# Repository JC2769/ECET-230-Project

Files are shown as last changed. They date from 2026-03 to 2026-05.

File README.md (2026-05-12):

# Personalized Weather Station

By: Joshua Chary & Shival Panchal

## Overview

The Personalized Weather Station is a custom embedded environmental monitoring system designed to measure:

- Temperature
- Humidity
- Atmospheric Pressure

The project was developed as part of ECET 230 and focuses on:

- Embedded system design
- PCB development
- Environmental sensing
- USB communication
- Manufacturing preparation
- Real-world engineering troubleshooting

The final system uses:
- ATmega328P-A microcontroller
- BME280 environmental sensor
- CH340C USB-to-serial interface
- Dual USB-C connections
- Python-based monitoring software

The project evolved from an early Raspberry Pi and DHT22 proof-of-concept into a smaller and more realistic custom PCB-based embedded system.

---

# Final System Features

## Hardware Features

- ATmega328P-A microcontroller
- BME280 environmental sensor
- CH340C USB-to-serial communication
- Dedicated USB-C power input
- Dedicated USB-C communication port
- 3.3V voltage regulation
- Crystal oscillator
- ISP programming header
- Test points for debugging
- Status LED
- ERC/DRC verified PCB design

## Software Features

- USB serial communication
- Python-based environmental monitoring
- Real-time graphing
- Weather trend estimation
- ntfy notification support
- Environmental data processing

---

# Included Project Files

This repository includes:

- Final Report
- Bill of Materials (BOM)
- Gerber Files
- Drill Files
- PCB Ordering Instructions
- Original Project Definition
- Updated Project Definition
- Source Code / Software

---

# Development Path

The project originally began as a Raspberry Pi and DHT22 proof-of-concept system used to validate environmental sensing concepts.

As development progressed, the project transitioned toward:
- A custom PCB design
- ATmega328P-A embedded system
- BME280 environmental sensing
- USB serial communication
- Python-based software integration

This redesign created a more realistic and manufacturable embedded product.

---

# Major Components

| Component | Purpose |
|---|---|
| ATmega328P-A | Main embedded microcontroller |
| BME280 | Temperature, humidity, and pressure sensing |
| CH340C | USB-to-serial communication |
| USB-C Connectors | Power and communication interfaces |
| LD1117S33TR | 3.3V voltage regulator |
| Crystal Oscillator | Stable MCU timing |
| ISP Header | Firmware programming |
| Test Points | Validation and debugging |

---

# PCB Design

The PCB was designed in KiCad and includes:

- Schematic capture
- PCB layout and routing
- ERC verification
- DRC verification
- Gerber generation
- Drill file export
- BOM generation
- 3D board rendering

The project also explored 4-layer PCB concepts to better understand:
- Inner-layer routing
- Via management
- PCB stackups
- Professional PCB workflows

---

# Manufacturing Readiness

The project includes:
- Gerber files
- Drill files
- BOM
- PCB ordering instructions

The PCB can be fabricated using:
- JLCPCB
- PCBWay
- OSHPark

The project should still be considered an educational prototype until physically assembled and fully validated.

---

# User Workflow

1. Connect the dedicated USB-C power connector
2. Connect the USB-C communication port to the computer
3. Launch the Python monitoring application
4. Environmental data is transferred through USB serial communication
5. The software graphs and processes the readings
6. ntfy notifications may be sent during demonstration operation

---

# Lessons Learned

This project provided practical experience with:
- Embedded system design
- PCB routing and layout
- Hardware troubleshooting
- USB communication
- Voltage regulation
- Manufacturing preparation
- Engineering documentation

Major lessons learned included:
- Incorrect sensor pin labeling can damage hardware
- Design reviews improve PCB quality
- Proper decoupling is critical for stable operation
- Real engineering projects evolve significantly during development

---

# Contributors

Joshua Chary
- Documentation
- Troubleshooting documentation
- PCB review assistance
- Project organization
- Presentation preparation

Shival Panchal
- PCB layout
- Hardware integration
- Embedded system implementation
- Schematic development

---

# Course Information

Institution: New Jersey Institute of Technology (NJIT)  
Course: ECET 230

---

# Final Notes

The Personalized Weather Station demonstrates the complete engineering workflow from proof-of-concept development through manufacturable PCB preparation.

The project combines:
- Embedded hardware
- Environmental sensing
- PCB manufacturing preparation
- USB communication
- Software integration
- Engineering documentation

into a realistic embedded system design experience.

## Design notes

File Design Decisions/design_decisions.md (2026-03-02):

# Environmental Sensor Subsystem – Design Decisions

## 1. Sensor Selection Decision

### Final Decision
Use the DHT22 (AM2302) as the primary environmental sensor for the proof-of-concept prototype.

### Original Plan
The initial system design included the BME280 sensor to measure pressure, temperature, and humidity.

### Issue Encountered
The BME280 modules received were unreliable and produced inconsistent or non-functional readings during testing. Multiple wiring configurations and software libraries were tested, but stable communication could not be achieved.

### Justification for Change
- DHT22 units functioned reliably during testing
- Reduced integration risk before the midterm deadline
- Simplified debugging process
- Ensured stable demonstration of core functionality

System stability and successful demonstration were prioritized over multi-sensor integration for the midterm version.

---

## 2. Subsystem Scope Adjustment

### Decision
Limit environmental monitoring to:
- Temperature
- Humidity

Pressure sensing will be reintroduced in a later revision once reliable hardware is available.

### Justification
- Ensures working prototype for demonstration
- Prevents unstable hardware from affecting overall system
- Keeps development aligned with project timeline

---

## 3. Sampling Rate Decision

### Decision
Implement a 2-second sampling interval.

### Justification
- Matches DHT22 minimum recommended interval
- Reduces timing-related read failures
- Provides stable real-time updates

---

## 4. Error Handling Strategy

### Decision
Implement structured retry logic (3 attempts per cycle) and store the last valid reading.

### Justification
- DHT22 uses a timing-sensitive single-wire protocol
- Linux is not a real-time operating system
- Retry logic significantly improves system stability
- Preserving last valid reading prevents UI instability

---

## 5. Execution Method

### Decision
Run scripts using sudo python3 during development.

### Justification
- GPIO access requires elevated permissions on Raspberry Pi OS
- Ensures reliable hardware communication during testing
- Acceptable for educational prototyping

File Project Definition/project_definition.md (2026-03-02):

# Project Definition – Personal Weather Station

## High-Level Description

This project is an embedded environmental monitoring system designed to collect real-time atmospheric data and provide user feedback based on programmed logic. The system uses environmental sensors connected to a Raspberry Pi to measure temperature, humidity, and (future) atmospheric pressure.

The system processes sensor data and provides feedback through a graphical interface and audible alerts.

---

## Purpose

The purpose of this project is to design and implement a functional microcontroller-based environmental monitoring system using concepts learned in ECET-230.

The project emphasizes:

- Hardware-software integration
- Structured system organization
- Reliable sensor communication
- Iterative refinement
- Clear engineering documentation

The goal is to demonstrate stable data acquisition, processing, and meaningful user feedback.

---

## Objectives

- Design a complete environmental monitoring system using a block diagram
- Implement the system using breadboard-level hardware
- Interface environmental sensors with Raspberry Pi GPIO and I2C
- Demonstrate stable temperature and humidity monitoring
- Integrate pressure sensing (BME280) once stable
- Implement trend-based weather detection logic
- Demonstrate correct data processing and output feedback
- Maintain organized engineering documentation in GitHub

---

## User Interaction

The user interacts with the system passively.

The system continuously monitors environmental conditions and displays:

- Temperature readings
- Humidity readings
- Status messages
- Alerts (when conditions indicate change)

If atmospheric pressure drops rapidly (future implementation), the system will notify the user through:

- GUI message update
- Audible alert

The system operates automatically without requiring manual user input during normal operation.

---

## System Components

### Inputs
- DHT22 (Temperature and Humidity)
- BME280 (Pressure – integration in progress)

### Processing
- Raspberry Pi 4
- Python-based logic
- Retry handling and trend detection algorithms

### Outputs
- Tkinter GUI display
- Console monitoring
- Audible alert (speaker/buzzer)

### Power
- 5V DC supply (Raspberry Pi regulated input)
- 3.3V logic for GPIO communication

---

## Constraints

- Must be implementable on a breadboard using development modules
- Must operate at 3.3V GPIO logic levels
- Linux timing limitations require retry logic for sensor stability
- Hardware reliability must be validated before full integration
- All design choices must remain feasible within the ECET-230 course scope

---

## Current Scope

### Completed
- DHT22 integration
- 2-second stable sampling
- Retry logic implementation
- GUI environmental display

### In Progress
- BME280 pressure integration
- Pressure trend detection
- Rain likelihood notification logic

---

## Project Vision

The final system will operate as a reliable personal weather station capable of:

- Monitoring environmental conditions in real time
- Detecting meaningful atmospheric trends
- Providing clear user feedback
- Operating stably under real-world conditions

The project evolves through structured debugging, iterative refinement, and subsystem validation.

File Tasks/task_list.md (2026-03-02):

# Project Tasks – Personal Weather Station

## High Priority

- Integrate BME280 sensor and verify stable I2C communication
- Debug unreliable BME280 readings
- Implement pressure monitoring logic
- Merge DHT22 and BME280 into unified environmental subsystem
- Test combined sensor operation on breadboard

## Medium Priority

- Refactor code for modular sensor handling
- Implement pressure trend detection algorithm
- Add rain prediction logic based on pressure drop
- Improve GUI layout and status indicators
- Optimize error handling for multi-sensor operation

## Low Priority

- Add data logging to file
- Add long-term trend storage
- Prepare enclosure layout
- Improve documentation and diagrams

---

## Dependencies

- Pressure-based rain prediction depends on successful BME280 integration
- GUI improvements depend on stable multi-sensor data
- Enclosure design depends on finalized hardware configuration

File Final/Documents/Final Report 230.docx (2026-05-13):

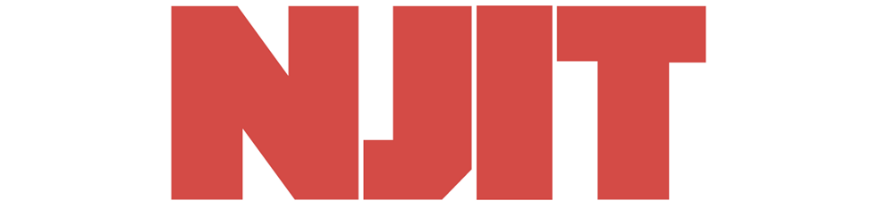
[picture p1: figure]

NEW JERSEY INSTITUTE OF TECHNOLOGY

SCHOOL OF APPLIED ENGINEERING AND TECHNOLOGY

TEAM NUMBER | 1
SUBMITTED TO | Professor Hansis
SUBMITTED BY | Joshua Chary (and Shival Panchal)
COURSE NAME\NUMBER\SECTION | ECET 230
EXPERIMENT | Personal Weather Station
DATE | 5/6/2026

# Introduction:

The goal of this project was to create a personalized weather station using a custom PCB and embedded system design. The system was designed to monitor environmental conditions in real time, including temperature, humidity, and atmospheric pressure. Along with building a useful monitoring device, the project focused on learning the full PCB design workflow, including schematic capture, component selection, PCB layout, design rule checks, manufacturing file preparation, and design revision.

The final design uses an ATmega328P-A microcontroller as the main processing unit and a BME280 environmental sensor to collect temperature, humidity, and barometric pressure data. The project changed throughout development. The original proof of concept used a DHT22 sensor and a Raspberry Pi-style GUI approach, but the final direction moved toward a smaller custom PCB using the BME280, USB serial communication, and a Python computer application for graphing, prediction, and phone notifications. This better reflected a realistic product design because the final system does not rely on a bulky Raspberry Pi and touchscreen setup.

During development, several real engineering issues came up, including incorrect BME280 pin labeling, damaged sensor modules, missing support components during PCB review, routing limitations, power input decisions, and USB communication decisions. These problems helped improve the design because each issue forced the team to review, troubleshoot, and make better design choices. The final result is a compact manufacturable embedded weather station design that demonstrates hardware/software integration and the full PCB development process.

# Updated Project Definition:

## High-Level Description

The Personalized Weather Station is a compact embedded environmental monitoring system designed to collect real-time weather data and send it to a user-facing computer application. The system measures temperature, humidity, and atmospheric pressure using a BME280 sensor connected to an ATmega328P-A microcontroller. The board communicates with a computer over USB serial communication, where a Python program receives the data, graphs the readings, estimates short-term trends, classifies the weather condition, and can send phone notifications through ntfy.

The project also serves as a full PCB design exercise. It includes schematic design, PCB routing, BOM generation, manufacturing file preparation, debugging, and documentation. The design is intended to be manufacturable and expandable for future features such as improved prediction, app integration, wireless communication, cloud logging, and enclosure development.

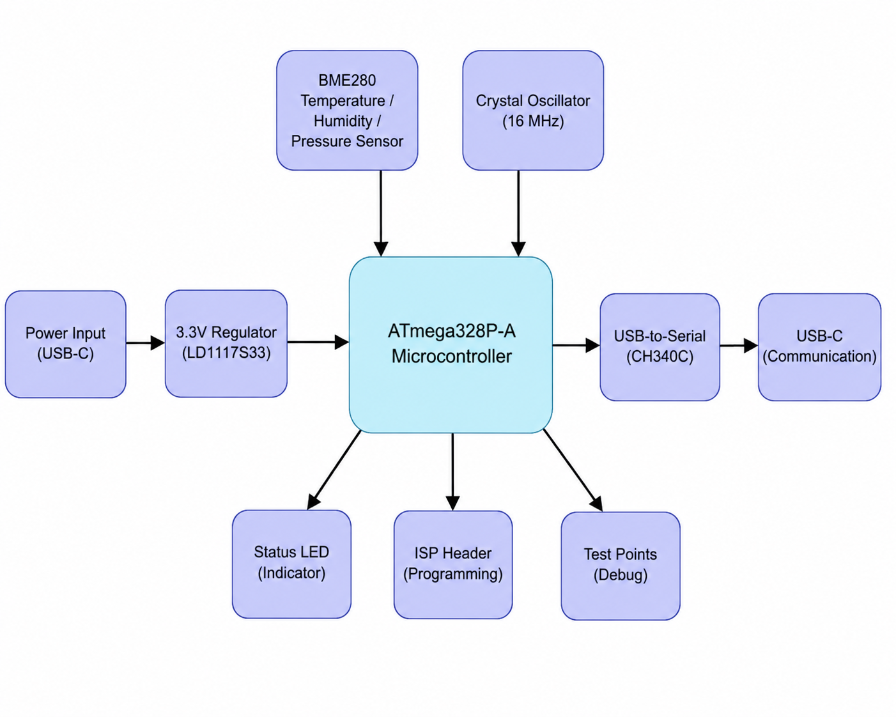
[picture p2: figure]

## Purpose

The purpose of the project is to design a smaller and more personalized alternative to oversized weather monitoring systems while also gaining practical experience with embedded hardware and PCB manufacturing. The system is meant to collect useful environmental data and display it in a way that is easy for the user to understand.

· Monitor environmental conditions in real time.

· Measure temperature, humidity, and atmospheric pressure.

· Use a custom PCB instead of a full development-board-only setup.

· Practice schematic capture, PCB layout, ERC/DRC checks, BOM creation, and manufacturing preparation.

· Use USB serial communication so a computer program can graph and process the sensor data.

· Explore prediction logic and phone notifications as future-facing product features.

## Objectives

· Design a custom PCB for a personalized weather station.

· Use an ATmega328P-A microcontroller as the main embedded controller.

· Use a BME280 sensor for temperature, humidity, and pressure measurement.

· Add the required support circuitry, including reset pull-up, pull-up resistors, crystal oscillator, decoupling capacitors, voltage regulation, USB-C connection, and ISP programming header.

· Create a BOM and prepare the board for manufacturing.

· Validate the concept through testing and demonstration software.

· Use Python to receive USB serial data, graph actual readings, estimate predicted values, classify weather trends, and send ntfy notifications.

· Document design choices, troubleshooting steps, and lessons learned.

## System Overview

The system is built around the ATmega328P-A microcontroller. The BME280 sensor collects environmental data and sends it to the microcontroller. The board includes supporting components for stable operation, including an external crystal oscillator, load capacitors, reset circuitry, decoupling capacitors, test points, an ISP programming header, USB-C hardware, a CH340C USB-to-serial interface, and a 3.3 V regulator.

The computer-side Python program connects to the board using USB serial communication. Once connected, it reads temperature, humidity, and pressure values, converts the units, graphs the readings, predicts short-term trends, classifies the weather condition, and sends phone notifications through ntfy during the demo.

## Major Components

Component | Purpose | Notes
ATmega328P-A | Main microcontroller | Handles sensor communication, processing, and serial output.
BME280 | Environmental sensor | Measures temperature, humidity, and barometric pressure.
CH340C | USB-to-serial interface | Allows the board to communicate with the computer through USB serial.
USB-C power USB-C communication | Power/communication interface | Used for connecting the device to the computer; CC resistors support proper USB-C behavior.
LD1117S33TR | 3.3 V voltage regulator | Regulates input voltage down to 3.3 V for the MCU/sensor side of the design.
Crystal Oscillator + 22 pF capacitors | MCU clock circuit | Provides a more stable clock than the internal oscillator.
R1 10 kOhm | Reset pull-up | Keeps the ATmega328P-A out of reset during normal operation.
R2/R3 4.7 kOhm | Communication pull-ups | Support reliable sensor communication lines.
R4 330 Ohm + LED | Status indicator | Provides a simple visual indication when the output pin is active.
C1/C5/C6/C7 0.1 uF, C2 10 uF | Decoupling/bulk capacitance | Helps stabilize power and reduce noise.
J2 ISP Header | Programming connector | Used to flash firmware onto the ATmega328P-A.
TP1-TP4 | Test points | Allows probing of signals and ground during testing/debugging.

# Actual Development Path

The project did not stay exactly the same as the original proposal. The original concept mentioned a Raspberry Pi 4, DHT22, GUI display, and future BME280 pressure integration. What actually happened was that the DHT22 was used only as an early proof of concept, and the project moved to the BME280 because it measures temperature, humidity, and pressure in one sensor. The Raspberry Pi/touchscreen-style product idea was also moved away from because it was too large and expensive for a realistic weather station product.

The final direction became a custom PCB with an ATmega328P-A and BME280, connected to a computer by USB serial. The computer application handles the higher-level user interface, graphing, prediction, and phone notifications. This approach keeps the physical product smaller and closer to a real embedded product while still allowing the demo to show live data clearly.

# Testing and Demonstration

Testing focused on proving that the sensing and data processing concept worked and that the PCB design was manufacturable. The BME280 sensor was used to collect environmental data. The Python program received serial data from the device, displayed a simple Tkinter interface, plotted live data using Matplotlib, predicted short-term trends, classified weather behavior, and sent ntfy notifications. The demonstration showed how the user could plug the device into a computer, run the application, and see weather readings and predictions update automatically.

The Python program used a fixed serial port setting for the demo, read comma-separated temperature, humidity, and pressure data, converted Celsius to Fahrenheit, converted pressure from hPa to inHg, graphed actual and predicted values, and sent phone notifications on a cooldown. This made the software useful for showing the project even before a final polished application was created.

# Troubleshooting and Design Challenges

· The original proof of concept used a DHT22 because it was available and easy to start with, but it was later dropped once the BME280 worked.

· Some BME280 modules were damaged during early testing because the pins were incorrectly labeled or misidentified, causing wiring mistakes.

· The initial PCB layout needed review because missing decoupling/bulk capacitors and other support details had to be added.

· Test points were added so important signals and ground could be probed during validation.

· USB-C communication was chosen instead of adding Wi-Fi hardware because the project did not need wireless hardware on the PCB for the current demo.

· A CH340C USB-to-serial interface was included so the board could communicate with the computer application.

· A 3.3 V voltage regulator was included because the sensor and MCU side needed a stable lower-voltage supply.

· The design was implemented as a 4-layer board to better understand layer stackups, vias, and inner-layer routing, even though the project started from a simpler PCB approach.

· The final product direction moved away from Raspberry Pi plus touchscreen because that approach was too bulky and costly for the intended product.

# User Documentation:

## Product Purpose

The Personalized Weather Station is a compact PCB-based environmental monitoring device. It measures temperature, humidity, and barometric pressure using a BME280 sensor. The board sends the data to a computer through USB serial communication, and the computer application displays the readings, graphs the data, predicts short-term trends, and can send phone notifications.

## How to Operate

1. Connect the dedicated USB-C power connection and USB-C communication connection.

2. Open the weather station computer application.

3. Start monitoring in the application.

4. The device will send sensor readings through USB serial communication.

5. The application will graph the readings and display the predicted weather trend.

6. Phone notifications may be sent through ntfy during demo operation.

## User Interface Elements

- USB-C power connection: provides power to the PCB.
- USB-C communication connection: transfers USB serial data between the PCB and computer application.
- Computer application: shows monitoring status, plots live readings, and displays the weather prediction.
- Phone notification: sends weather updates through ntfy when the software triggers a message.
- Status LED: provides a simple visual indicator when the assigned output pin is active.
- ISP header: used only for programming the ATmega328P-A, not for normal user operation.
- Test points: used for engineering validation and troubleshooting, not for normal user interaction.

## External Connections Summary

Connection | Location | Purpose
DualUSB-C Power Port | J1 | Dedicated board power input
USB-C Communication Port | J3 | USB serial communication with computer
ISP Programming | J2 | Firmware flashing for the ATmega328P-A.
Test Points | TP1-TP4 | Signal and ground probing during validation.
Battery/External Power Option | Battery holder or USB C | portable or external power source depending on final build configuration.

# Design Decision Document:

## 1. Primary Sensor Selection - DHT22 to BME280

The project started with the DHT22 because it was available and worked for a quick proof of concept. However, the DHT22 only measures temperature and humidity. The BME280 was selected for the final design because it measures temperature, humidity, and barometric pressure in one compact sensor package. The BME280 also better supports the weather prediction goal because pressure trends are important for classifying changing weather conditions.

## 2. Microcontroller Selection - ATmega328P-A

The ATmega328P-A was selected because it is well documented, familiar, and appropriate for a compact embedded system. Instead of placing a full Arduino board inside the product, the bare microcontroller was integrated into the PCB. This makes the design smaller and more realistic for a manufacturable embedded product.

## 3. Communication to Computer - USB Serial

USB serial communication was chosen because the current product does not need Wi-Fi hardware on the PCB. A USB connection allows the user to plug the device into a computer, run the application, collect data, and show live graphs. This is simpler and more reliable for the class demo than adding an ESP module or a full wireless system.

## 4. USB-to-Serial Interface - CH340C

The CH340C was included so the ATmega328P-A can communicate with the computer over USB serial. This supports the actual demo workflow, where the Python application receives sensor readings through a COM port and handles graphing, prediction, and notifications.

## 5. Voltage Regulation - 5 V to 3.3 V

A 3.3 V regulator was added because the BME280 and low-voltage logic side need a stable 3.3 V supply. This also helps protect the sensor and makes the board safer and more predictable when powered from USB or another input source.

## 6. Output Method - Computer Application and Phone Notifications

The original Raspberry Pi/touchscreen idea was dropped because it made the product too bulky and expensive. The final demo uses a computer application to show graphs and predictions, and ntfy notifications to send alerts to a phone. This is more practical than building a full display into the hardware.

## 7. PCB Layer Count - 4-Layer Learning Exercise

The project started with normal PCB routing, but the design was implemented as a 4-layer board to learn more about stackups, routing on inner layers, and via management. This was valuable because it showed how a real board can be improved and organized beyond a simple 2-layer layout.

## 8. Support Components

Support components were added to make the design stable and complete. These included the reset pull-up resistor, communication pull-ups, LED current-limiting resistor, decoupling capacitors, bulk capacitor, crystal oscillator, load capacitors, test points, ISP programming header, USB-C hardware, and voltage regulator. Several of these parts were added or corrected after design review, which made the final design stronger.

# Manufacturing Readiness

The PCB design includes the main schematic, board layout, BOM, and manufacturing-oriented files. The design uses commercially available components, including the ATmega328P-A, BME280, CH340C, dedicated USB-C power, dedicated USB-C communication, LD1117 3.3 V regulator, passives, crystal, test points, LED, and programming header. Gerber and drill files are separate manufacturing outputs: Gerbers describe the copper, mask, silkscreen, and board layers, while drill files describe the holes and vias. Both are needed by the PCB manufacturer.

The board was prepared to be manufacturing-ready, but the project should still be treated as an educational prototype until it is physically fabricated, assembled, and fully validated. The test points and programming header make future validation easier after assembly.

# Individual Contributions - Joshua Chary:

· Project documentation and updated project definition.

· Development logging and explanation of what changed from the original idea.

· PCB review assistance and identifying missing or unclear design elements.

· BOM review and component/function clarification.

· Troubleshooting documentation, including sensor issues, USB communication decisions, and power/regulator decisions.

· Presentation preparation and explanation of design challenges.

· Helping connect the technical design choices to what the product actually does for the user.

# Future Improvements:

· Fabricate and assemble the PCB, then validate it with real measurements.

· Create a cleaner final desktop application or mobile app.

· Improve prediction logic using a better regression model and more collected data.

· Add optional cloud logging or data export.

· Design a custom enclosure.

· Add waterproofing or outdoor-rated sensor placement.

· Improve power management for battery operation.

· Consider wireless communication in a future revision only if the product needs standalone remote operation.

Schematic:

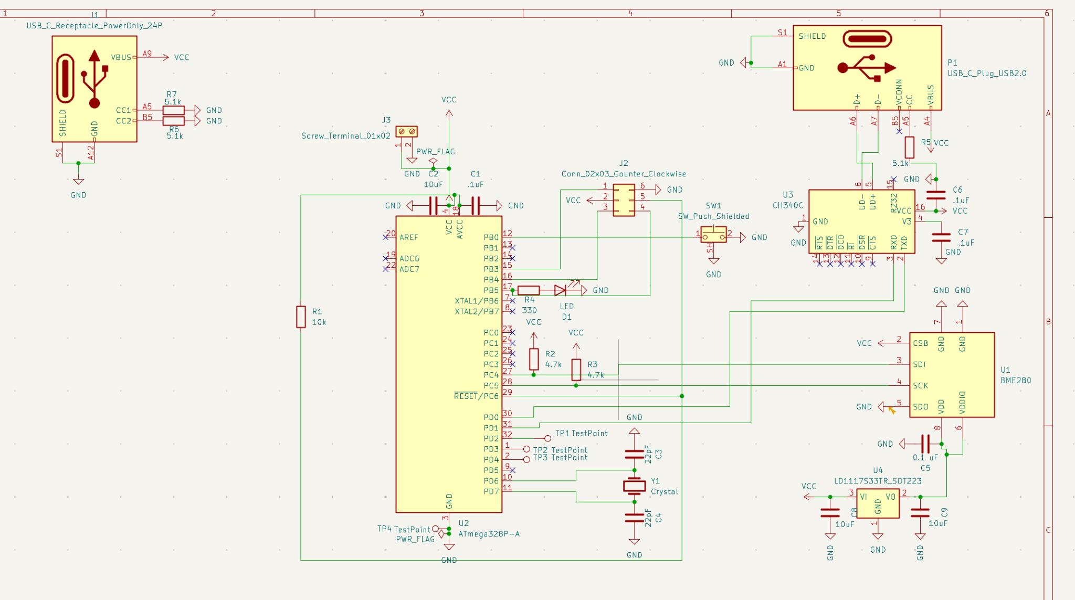
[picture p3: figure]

ERC/DRC Readings:

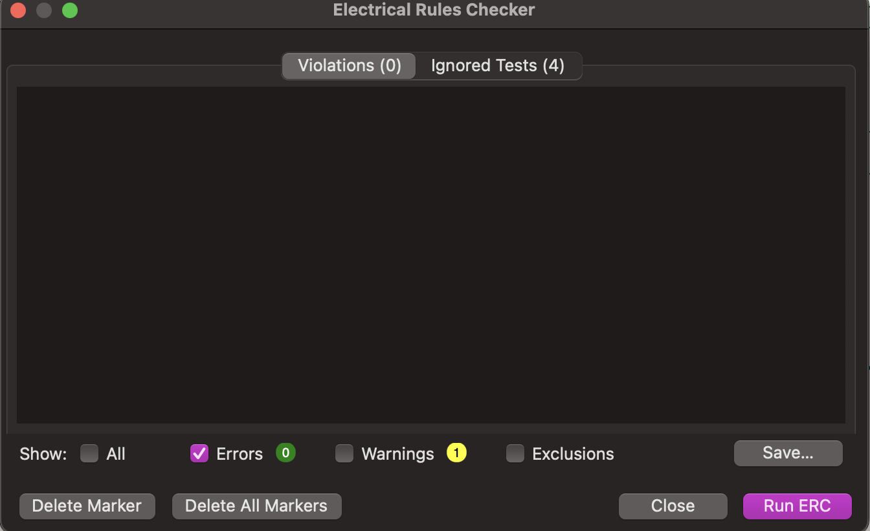
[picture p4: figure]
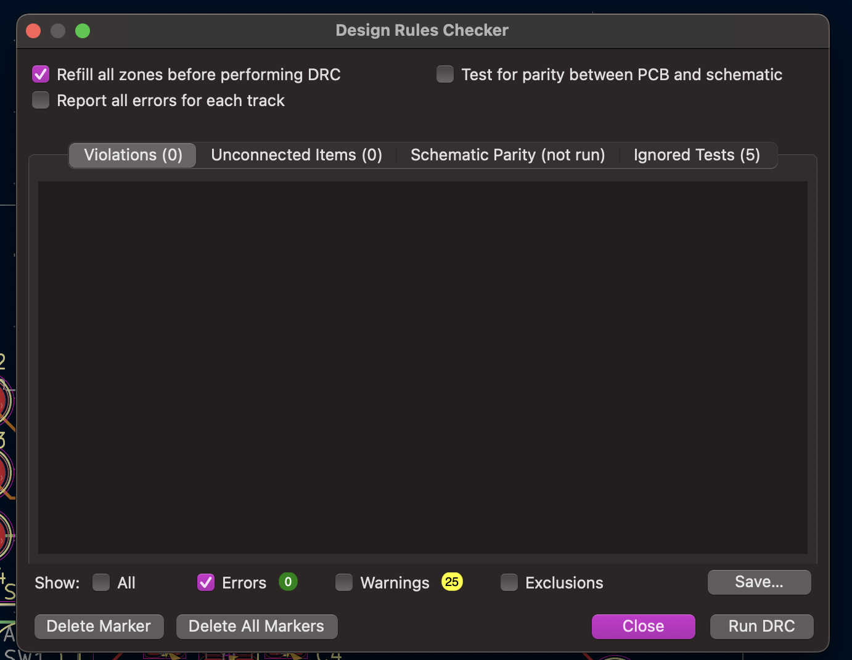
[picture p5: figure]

3D Board Renderings:

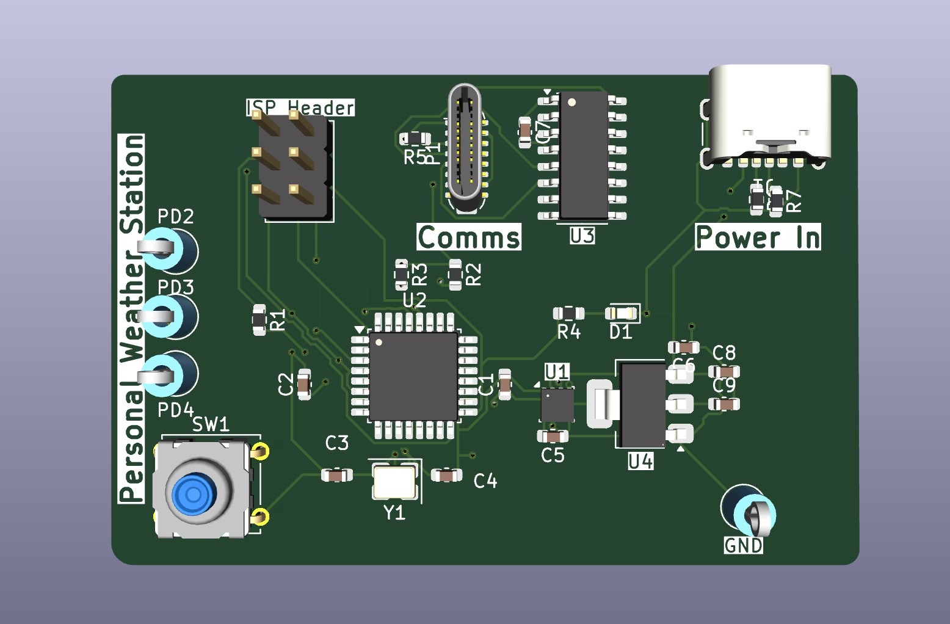
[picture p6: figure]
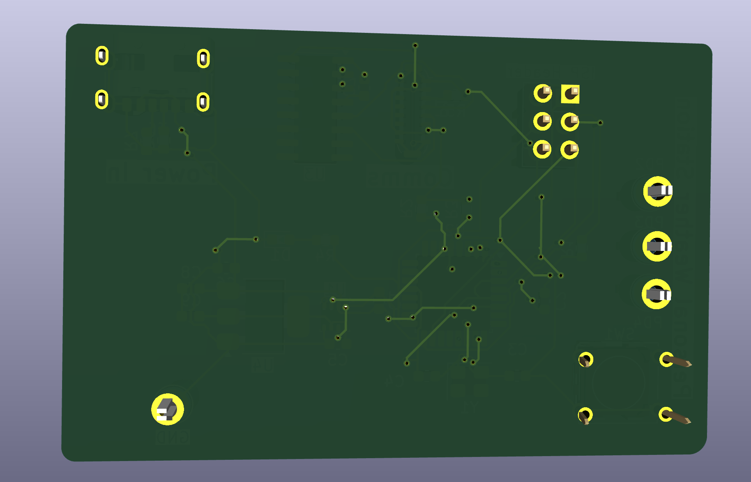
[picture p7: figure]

# Conclusion

The Personalized Weather Station successfully evolved from a simple proof-of-concept idea into a more realistic custom PCB-based embedded system. The project started with a DHT22/Raspberry Pi-style concept, but the final direction used an ATmega328P-A, BME280 sensor, USB serial communication, Python graphing, prediction logic, and phone notifications. The project gave hands-on experience with real engineering challenges, including damaged sensors, incorrect pin labeling, PCB review, missing support components, USB communication decisions, and voltage regulation. Overall, the final design better reflects what actually happened during development and provides a strong foundation for a manufacturable weather monitoring product.

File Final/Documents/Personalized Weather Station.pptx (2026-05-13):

## Personalized Weather Station

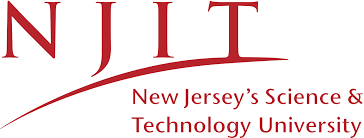
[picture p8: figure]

By: Shival Panchal & Joshua Chary

8

May

2026

## Motivation?

- Weather affects daily decisions
- Existing systems can be expensive or oversized
- Goal was to create a compact personalized monitoring device
- Learn schematic capture, layout, and design rule verification
- Learn full PCB manufacturing workflow from concept to implementation
- Simulate a real product development cycle from concept to manufacturable design

Confidential

## Objectives:

- Measure environmental conditions
- Design a custom PCB
- Integrate sensors and microcontroller
- Manufacture and assemble the board
- Validate functionality through testing
- Create a compact and reliable system
- Try implementing a regression model to predict the future weather conditions

## Critical Components:

● ATmega328P-A — core microcontroller handling sensing, processing, and communication
● BME280 — environmental sensor measuring temperature, humidity, and pressure
● CH340C — USB-to-serial communication interface
● Dual USB-C Connectors — dedicated power and communication interfaces
● LD1117S33TR — 3.3V voltage regulator
● Crystal Oscillator — provides stable MCU timing
● ISP Header — used for firmware programming
● Test Points — used for debugging and validation
● Status LED — visual activity indicator

## Schematic:

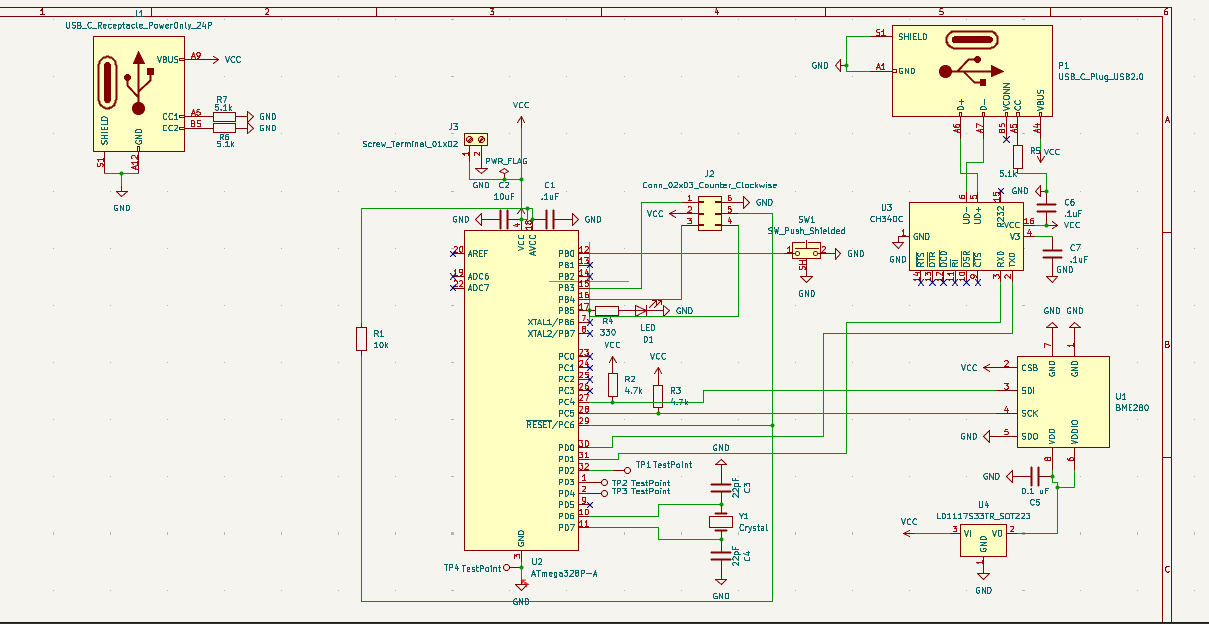
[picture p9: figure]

## PCB Design:

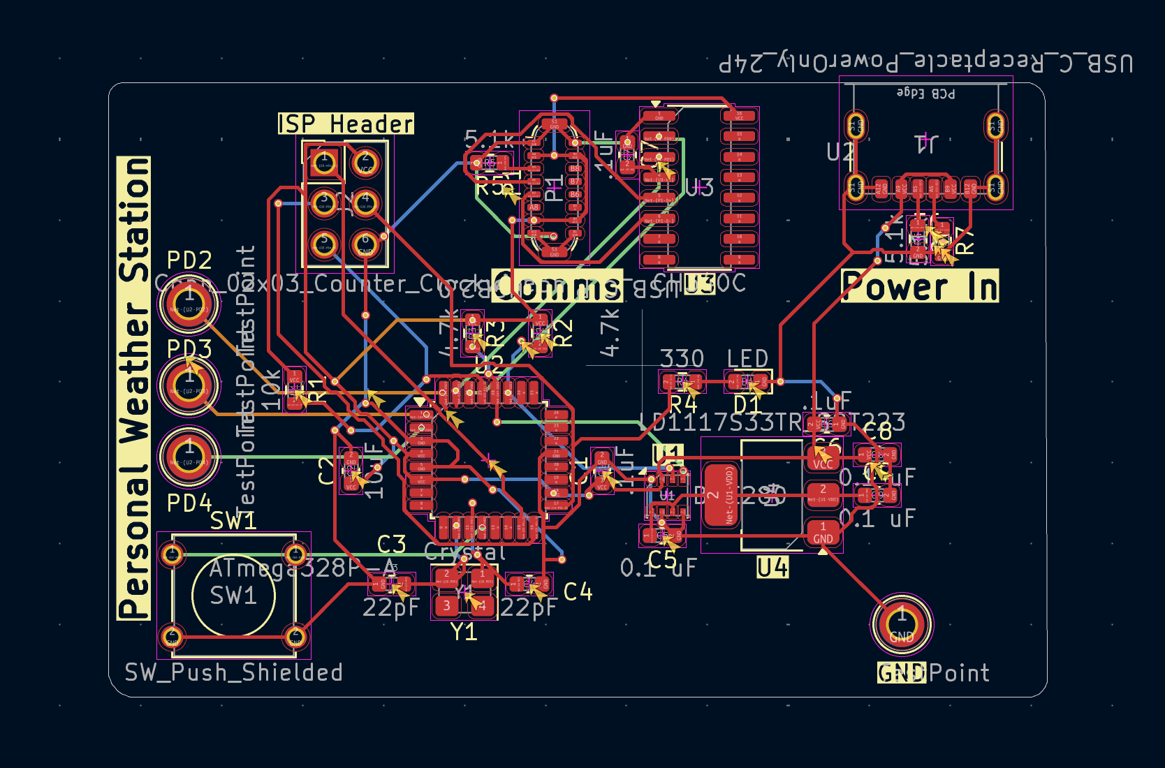
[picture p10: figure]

## Design Challenges:

- Initial proof of concept used a DHT22 — functioned correctly and validated the sensing approach
- BME280 was damaged during early testing due to incorrect pin labeling — pins were misidentified causing improper connections
- Partner completed initial PCB layout, brought in for design review — identified missing decoupling and bulk capacitors and added them
- Test points added to GND and sensor lines during review to allow probing for future sensor swaps or debugging
- Once BME280 was correctly wired and operational, DHT22 was dropped entirely in favor of the more capable sensor
- After finalizing edits, experimented with converting the board to a 4-layer stackup
- Learned how to assign vias to specific layers and route signals across inner copper layers
- Gained hands-on understanding of how 4-layer boards are structured beyond standard 2-layer design

## Manufacturing Readiness

- All components are commercially available — Arduino, BME280, passives, connectors, crystal
- Gerber files can be submitted directly to any PCB fab house (JLCPCB, PCBWay, OSHPark)
- Board is fully functional as designed — can be ordered, assembled, and operational without any design changes
- Test points ensure easy validation immediately after assembly

## How Does this Product Work?

Program will collect data from the device, and push notifications to the User

User Will Plug the device into their computer (via USB)

User will install our computer application

User will run the program


## What is our product doing?

Computer Program collects data through USB serial communication

Python Predicts future trends and classifies a weather condition

ATmega328P-A collects environmental data through the BME280

Python receives data and graphs actual values

## User Interface / Data Collection

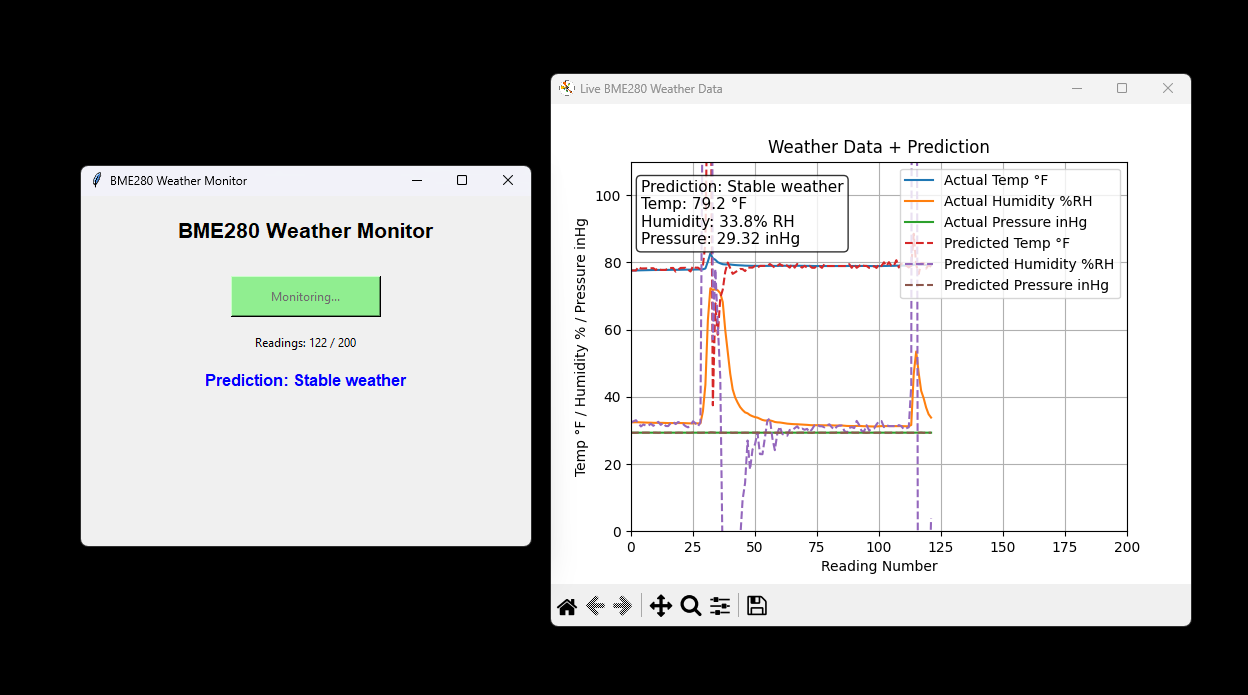
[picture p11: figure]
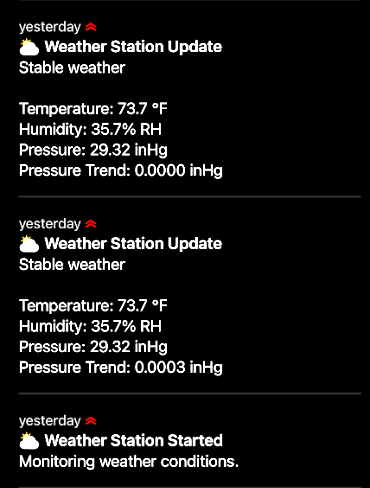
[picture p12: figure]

## Mini Demonstration:

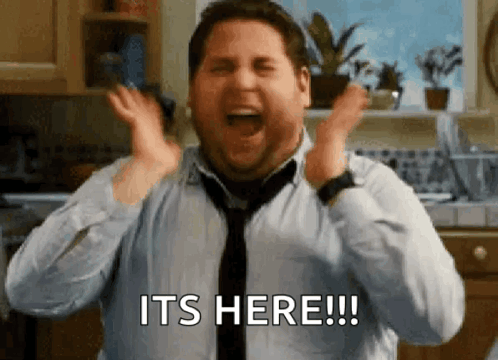
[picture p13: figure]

## Conclusion:

- Successfully completed a full PCB design cycle from schematic capture to manufacturable layout in KiCad
- Hands-on experience with real engineering challenges — damaged components, design reviews, and iterative fixes
- Learned 4-layer board design, via management, decoupling strategy, and SPI sensor interfacing
- Project has direct real-world application — already being used in a professional environment for environmental monitoring
- Demonstrated that good engineering is iterative — the final design is stronger because of every mistake made along the way

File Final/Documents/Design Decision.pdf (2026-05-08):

# Design Decision Document

## 1. Primary Sensor Selection — DHT22 to BME280

### What we were trying to achieve

A reliable environmental sensor capable of measuring temperature, humidity, and atmospheric pressure.

### Options considered

- DHT22
- BME280

### What we chose

BME280

### Why

The DHT22 was initially used during early proof-of-concept testing because it was already available and allowed rapid validation of the environmental sensing workflow.

Once replacement BME280 units were obtained and correctly wired, the BME280 became the clear choice because it combines temperature, humidity, and barometric pressure sensing into a single device.

The BME280 better supported the weather prediction goals because pressure trends are important for classifying changing weather conditions.

## 2. Microcontroller Selection — ATmega328P-A

### What we were trying to achieve

A capable embedded microcontroller suitable for a manufacturable custom PCB design.

### Options considered

- Raspberry Pi
- Arduino Uno
- ATmega328P-A

### What we chose

ATmega328P-A

### Why

Early proof-of-concept testing used a Raspberry Pi platform, but it became clear during design review that a Raspberry Pi and touchscreen-based system would not reflect a practical manufacturable embedded product.

Using the ATmega328P-A directly on the PCB reduced unnecessary overhead, lowered system complexity, and better reflected professional embedded system design practices.

## 3. Communication to Computer — USB Serial

### What we were trying to achieve

Reliable communication between the PCB and external software for environmental data transfer and analysis.

### Options considered

- GPIO-only monitoring
- Wireless-only communication
- USB serial communication

### What we chose

USB serial communication

### Why

USB communication provided a reliable and straightforward method for transferring environmental data between the PCB and the external computer application.

This simplified debugging, testing, and software integration while allowing environmental data to be visualized and analyzed using Python-based software.

## 4. Power Input & Communication Interface — Dual USB-C Design

### What we were trying to achieve

A cleaner and more modern solution for both powering the board and transferring environmental data between the PCB and external software.

### Options considered

- Screw terminals
- Barrel jack
- Single USB-C connector
- Dual USB-C connectors

### What we chose

Two dedicated USB-C connectors:

- One USB-C connector for board power input
- One USB-C connector for communication and USB serial data transfer

### Why

Earlier versions of the project relied on screw terminals for power input, but this approach felt less practical and less user-friendly for a modern embedded product.

Moving to USB-C simplified external connectivity and created a cleaner interface for both development and future expansion.

Separating power and communication into two dedicated USB-C connectors also simplified debugging and system organization.

## 5. Crystal Oscillator vs Internal Oscillator

### What we were trying to achieve

Stable and accurate MCU timing.

### Options considered

- Internal oscillator
- External crystal oscillator

### What we chose

External crystal oscillator with 22pF load capacitors

### Why

The external crystal oscillator provides more stable and accurate timing than the internal oscillator, improving communication reliability and overall system stability.

## 6. PCB Layer Count — 2 Layer vs 4 Layer

### What we were trying to achieve

A clean and manufacturable PCB layout with improved routing flexibility.

### Options considered

- 2-layer PCB
- 4-layer PCB

### What we chose

Primary 2-layer design with experimentation using a 4-layer stackup.

### Why

Initial routing on a standard 2-layer PCB became congested during layout development.

Experimenting with a 4-layer PCB improved understanding of professional PCB routing workflows and allowed exploration of inner-layer signal routing and via assignment techniques.

## 7. User Interface Approach

### What we were trying to achieve

A practical method for users to interact with and monitor environmental data.

### Options considered

- Touchscreen GUI
- Onboard display
- External software interface
- Mobile notifications

### What we chose

USB communication with external software and future notification support.

### Why

A touchscreen-based Raspberry Pi system introduced unnecessary complexity and cost.

Moving monitoring and visualization to external software simplified the PCB design while improving expandability for future features such as notifications and weather prediction.

## 8. Support Components

### What we were trying to achieve

Stable operation and proper support circuitry for the embedded system.

### What we chose

- 10kΩ reset pull-up resistor
- 4.7kΩ pull-up resistors
- 330Ω LED resistor
- 22pF crystal load capacitors
- Decoupling capacitors
- Voltage regulator
- Test points
- ISP programming header

### Why

Values and support components were selected based on datasheet recommendations and common embedded system design practices to ensure stable operation, clean power delivery, and reliable communication.

Several components were added or corrected during PCB review which improved the final design.

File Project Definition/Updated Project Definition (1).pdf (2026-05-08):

# Updated Project Definition

## High Level Description

The Personalized Weather Station is a compact embedded environmental monitoring system designed to collect real-time weather data and send it to a user-facing computer application. The system measures temperature, humidity, and atmospheric pressure using a BME280 sensor connected to an ATmega328P-A microcontroller. The board communicates with a computer over USB serial communication, where a Python program receives the data, graphs the readings, estimates short-term trends, classifies the weather condition, and can send phone notifications through ntfy.

The project also serves as a full PCB design exercise. It includes schematic design, PCB routing, BOM generation, manufacturing file preparation, debugging, and documentation. The design is intended to be manufacturable and expandable for future features such as improved prediction, app integration, wireless communication, cloud logging, and enclosure development.

## Purpose

The purpose of the project is to design a smaller and more personalized alternative to oversized weather monitoring systems while also gaining practical experience with embedded hardware and PCB manufacturing.

The system is meant to:

- Monitor environmental conditions in real time
- Measure temperature, humidity, and atmospheric pressure
- Use a custom PCB instead of a full development-board-only setup
- Practice schematic capture, PCB layout, ERC/DRC checks, BOM creation, and manufacturing preparation
- Use USB serial communication so a computer program can graph and process the sensor data
- Explore prediction logic and phone notifications as future-facing product features

## Objectives

- Design a custom PCB for a personalized weather station
- Use an ATmega328P-A microcontroller as the main embedded controller
- Use a BME280 sensor for temperature, humidity, and pressure measurement
- Add the required support circuitry including reset pull-up, pull-up resistors, crystal oscillator, decoupling capacitors, voltage regulation, USB-C connection, and ISP programming header
- Create a BOM and prepare the board for manufacturing

- Validate the concept through testing and demonstration software
- Use Python to receive USB serial data, graph actual readings, estimate predicted values, classify weather trends, and send ntfy notifications
- Document design choices, troubleshooting steps, and lessons learned

## System Overview

The system is built around the ATmega328P-A microcontroller. The BME280 sensor collects environmental data and sends it to the microcontroller. The board includes supporting components for stable operation including:

- External crystal oscillator
- Load capacitors
- Reset circuitry
- Decoupling capacitors
- Test points
- ISP programming header
- USB-C hardware
- CH340C USB-to-serial interface
- 3.3 V regulator

The PCB currently includes two dedicated USB-C connectors:

- One USB-C connector for board power input
- One USB-C connector for communication and USB serial data transfer

The computer-side Python program connects to the board using USB serial communication. Once connected, it reads temperature, humidity, and pressure values, converts the units, graphs the readings, predicts short-term trends, classifies the weather condition, and sends phone notifications through ntfy during the demo.

## Major Components

Component | Purpose
ATmega328P-A | Main microcontroller
BME280 | Temperature, humidity, and pressure sensing
CH340C | USB-to-serial communication
USB-C Connectors | Power and communication interfaces
LD1117S33TR | 3.3V voltage regulator
Crystal Oscillator | Stable MCU timing
ISP Header | Firmware programming

Test Points | Validation and debugging
LED + Resistor | Status indication

## Actual Development Path

The project did not stay exactly the same as the original proposal. The original concept mentioned a Raspberry Pi 4, DHT22, GUI display, and future BME280 pressure integration. What actually happened was that the DHT22 was used only as an early proof of concept, and the project moved to the BME280 because it measures temperature, humidity, and pressure in one sensor.

The Raspberry Pi/touchscreen-style product idea was also moved away from because it was too large and expensive for a realistic weather station product.

The final direction became a custom PCB with an ATmega328P-A and BME280 connected to a computer by USB serial communication. The computer application handles the higher-level user interface, graphing, prediction, and phone notifications.

## Testing and Demonstration

Testing focused on proving that the sensing and data processing concept worked and that the PCB design was manufacturable.

The Python program:

- Received serial data from the device
- Displayed a Tkinter interface
- Graphed live environmental data
- Predicted short-term trends
- Classified weather behavior
- Sent ntfy notifications

The demonstration showed how a user could:

- Plug the device into a computer
- Run the application
- View environmental readings
- Monitor predictions and notifications automatically

## Troubleshooting and Design Challenges

- The original proof of concept used a DHT22 because it was available and easy to start with
- The DHT22 was later replaced with the BME280
- Some BME280 modules were damaged during testing because the pins were incorrectly labeled or misidentified

- The initial PCB layout required review because support components were missing
- Test points were added for easier validation and debugging
- USB-C communication was selected instead of Wi-Fi hardware because wireless communication was unnecessary for the current demo
- A CH340C USB-to-serial interface was added to support communication with the computer application
- A 3.3 V regulator was included because the sensor and MCU required stable lower-voltage operation
- The project explored 4-layer PCB routing concepts to better understand professional PCB workflows
- The final direction moved away from the Raspberry Pi and touchscreen concept because it was too bulky and costly

## Future Improvements

- Fabricate and assemble the PCB, then validate it with real measurements
- Create a cleaner desktop or mobile application
- Improve prediction logic using a better regression model
- Add cloud logging or data export
- Design a custom enclosure
- Add waterproofing or outdoor sensor protection
- Improve power management for battery operation
- Explore wireless communication in future revisions if needed

The Personalized Weather Station successfully evolved from a simple proof-of-concept idea into a more realistic custom PCB-based embedded system. The final direction used an ATmega328P-A, BME280 sensor, USB serial communication, Python graphing, prediction logic, and phone notifications.

The project provided hands-on experience with:

- PCB design
- Embedded system development
- Hardware troubleshooting
- Manufacturing preparation
- USB communication
- Engineering documentation

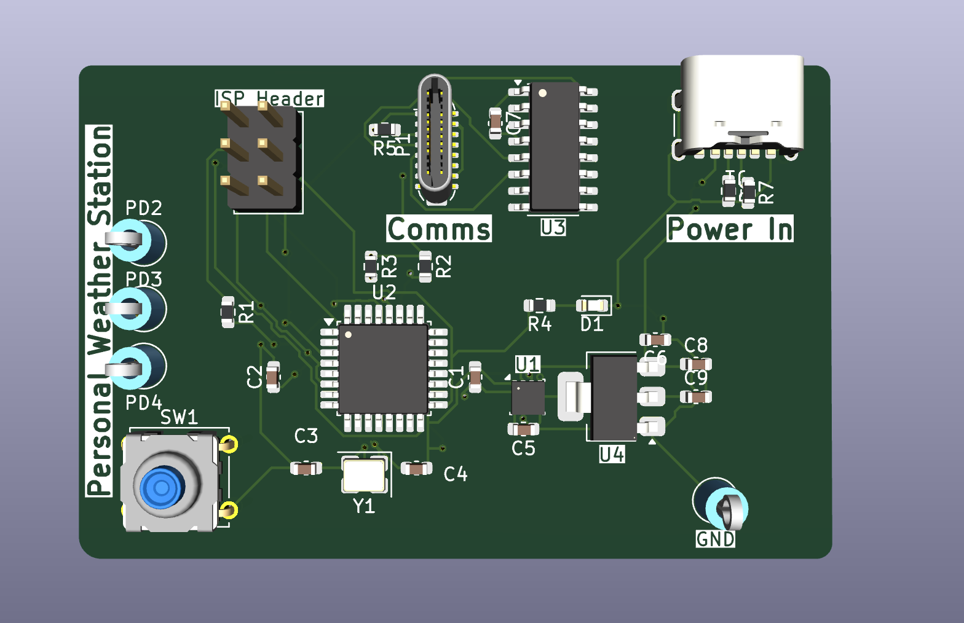
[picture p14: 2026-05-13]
Final/Documents/3D-rendering.png

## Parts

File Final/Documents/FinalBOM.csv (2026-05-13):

Reference | Qty | Value | DNP | Exclude from BOM | Exclude from Board | Footprint | Datasheet | Manu Part#
Y1 | 1 | Crystal |  |  |  | Crystal:Crystal_SMD_3225-4Pin_3.2x2.5mm | ~ | ECS-2520MVLC-010-BN-TR
TP1,TP2,TP3,TP4 | 4 | TestPoint |  |  |  | TestPoint:TestPoint_Keystone_5005-5009_Compact | ~ | 5001
SW1 | 1 | SW_Push_Shielded |  |  |  | Button_Switch_THT:SW_Tactile_Straight_KSA0Axx1LFTR | ~ | 78-50-0118-00-ND
R5,R6,R7 | 3 | 5.1k |  |  |  | Resistor_SMD:R_0603_1608Metric | ~ | RC0603FR-075K1L
R4 | 1 | 330 |  |  |  | Resistor_SMD:R_0603_1608Metric | ~ | RC0201FR-0733RL
R2,R3 | 2 | 4.7k |  |  |  | Resistor_SMD:R_0603_1608Metric | ~ | RC0402JR-074K7L
R1 | 1 | 10k |  |  |  | Resistor_SMD:R_0603_1608Metric | ~ | RC0603FR-0710KL
J3 | 1 | Screw_Terminal_01x02 |  |  |  | Battery:BatteryHolder_TruPower_BH-331P_3xAA | ~ | BC2AAPC
J2 | 1 | Conn_02x03_Counter_Clockwise |  |  |  | Connector_PinHeader_2.54mm:PinHeader_2x03_P2.54mm_Vertical | ~ | SSK04-FPH-254-B3
D1 | 1 | LED |  |  |  | LED_SMD:LED_0603_1608Metric | ~ | LTST-C191KRKT
C8,C9 | 2 | 10uF |  |  |  | Capacitor_SMD:C_0603_1608Metric | ~ | CL10B104KB8NNNC
C6,C7 | 2 | .1uF |  |  |  | Capacitor_SMD:C_0603_1608Metric | ~ | CL10B104KB8NNNC
C5 | 1 | 0.1 uF |  |  |  | Capacitor_SMD:C_0603_1608Metric | ~ | CL10B104KB8NNNC
C3,C4 | 2 | 22pF |  |  |  | Capacitor_SMD:C_0603_1608Metric | ~ | GCM188R71E224KA55D
C2 | 1 | 10uF |  |  |  | Capacitor_SMD:C_0603_1608Metric | ~ | 0603X106M100CT
C1 | 1 | .1uF |  |  |  | Capacitor_SMD:C_0603_1608Metric | ~ | GRM033R60J104KE19D
P1 | 1 | USB_C_Plug_USB2.0 |  |  |  | Connector_USB:USB_C_Plug_ShenzhenJingTuoJin_918-118A2021Y40002_Vertical | https://www.usb.org/sites/default/files/documents/usb_type-c.zip | 5149-LUB-C104D-0-007-G-19TR-ND
J1 | 1 | USB_C_Receptacle_PowerOnly_24P |  |  |  | Connector_USB:USB_C_Receptacle_GCT_USB4125-xx-x-0190_6P_TopMnt_Horizontal | https://www.usb.org/sites/default/files/documents/usb_type-c.zip | 5149-LUB-C104D-0-007-G-19TR-ND
U1 | 1 | BME280 |  |  |  | Package_LGA:Bosch_LGA-8_2.5x2.5mm_P0.65mm_ClockwisePinNumbering | https://www.bosch-sensortec.com/media/boschsensortec/downloads/datasheets/bst-bme280-ds002.pdf | 828-1063-1-ND
U3 | 1 | CH340C |  |  |  | Package_SO:SOIC-16_3.9x9.9mm_P1.27mm | https://datasheet.lcsc.com/szlcsc/Jiangsu-Qin-Heng-CH340C_C84681.pdf | 1188-1173-ND
U4 | 1 | LD1117S33TR_SOT223 |  |  |  | Package_TO_SOT_SMD:SOT-223-3_TabPin2 | http://www.st.com/st-web-ui/static/active/en/resource/technical/document/datasheet/CD00000544.pdf | LD1117S33CTR
U2 | 1 | ATmega328P-A |  |  |  | Package_QFP:TQFP-32_7x7mm_P0.8mm | http://ww1.microchip.com/downloads/en/DeviceDoc/ATmega328_P%20AVR%20MCU%20with%20picoPower%20Technology%20Data%20Sheet%2040001984A.pdf | ATMEGA328P-AU-ND

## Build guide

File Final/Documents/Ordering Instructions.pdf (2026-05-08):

PCB Ordering Instructions — Personalized Weather Station

Overview
- The Personalized Weather Station PCB was designed in KiCad.
- The board is manufacturing-ready and can be fabricated through:
- JLCPCB
- PCBWay
- OSHPark

Files Required for Manufacturing
- Gerber ZIP folder
- Drill file
- Bill of Materials (BOM)

Recommended PCB Specifications
- Board Material: FR4
- Layer Count:
- 2-layer version
- 4-layer experimental version
- Board Thickness: 1.6mm
- Copper Weight: 1 oz
- Surface Finish: HASL Lead-Free
- Solder Mask: Green
- Silkscreen: White

USB-C Integration
The PCB currently includes two USB-C connectors:
1. USB-C Power Input
- Dedicated to powering the board
- Intended to simplify external power delivery
- Replaces older screw terminal-only power concepts
2. USB-C Communication Port
- Dedicated to communication between the PCB and external computer software
- Intended for USB serial data transfer
- Allows environmental data to be processed and visualized through a Python-based computer application

Note:
- USB-C implementation is still considered a work-in-progress during this stage of development and testing.

Manufacturing Notes
- ERC verification completed

- DRC verification completed
- Standard PCB manufacturing tolerances are acceptable
- No impedance-controlled routing required
- All components selected using commercially available parts

Assembly Notes
Carefully verify orientation and placement of:
- ATmega328P-A microcontroller
- BME280 environmental sensor
- Crystal oscillator
- USB-C connectors
- LED polarity
- Capacitors

Firmware Programming
- Firmware is flashed through ISP Header (J2)
- Compatible programming methods:
- USBasp programmer
- Arduino configured as ISP

Power Input
The board may currently be powered through:
- Dedicated USB-C power connector
- External screw terminal power input (if populated)

Important:
- Do not connect multiple power sources simultaneously

Post-Assembly Validation
After assembly:
- Verify no shorts exist between VCC and GND
- Verify proper USB-C connector soldering
- Verify component orientation
- Apply power and confirm the board powers correctly
- Flash firmware to the ATmega328P-A
- Verify environmental sensor readings and USB communication functionality

Final Status
- PCB is manufacturing-ready
- Fabrication files are complete
- USB-C communication and power integration are currently in development and testing
- Design prepared for future expansion and software integration

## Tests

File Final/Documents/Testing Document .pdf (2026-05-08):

# Testing Document — Personalized Weather Station

# Purpose of Testing

The purpose of testing was to verify that the Personalized Weather Station design and supporting software successfully demonstrated the intended environmental monitoring functionality.

Testing focused on:

- Environmental sensor operation
- USB serial communication
- Data processing
- Software visualization
- Notification functionality
- PCB manufacturability and validation

The testing process also helped identify hardware design issues, communication problems, and missing support circuitry during development.

# Test 1 — Power Verification

## Objective

Verify that the PCB powers correctly and distributes voltage properly.

## Procedure

1. Connect the dedicated USB-C power connector.
2. Apply power to the board.
3. Measure voltage rails using a multimeter.
4. Verify voltage regulator output.
5. Observe status LED behavior.

## Expected Results

- Board powers on successfully.
- Voltage regulator outputs stable 3.3V.
- No excessive heat or short circuits are observed.
- Status LED functions correctly.

## Results

Power distribution functioned as expected during testing. Voltage regulation was added specifically to provide stable 3.3V operation for the MCU and BME280 sensor.

# Test 2 — Environmental Sensor Validation

## Objective

Verify that the BME280 sensor correctly measures environmental conditions.

## Procedure

1. Connect the BME280 sensor to the PCB.
2. Flash firmware to the ATmega328P-A.
3. Monitor serial output from the MCU.
4. Observe temperature, humidity, and pressure readings.
5. Compare changing values with surrounding environmental conditions.

## Expected Results

- Sensor initializes correctly.
- Temperature readings update continuously.
- Humidity readings update continuously.
- Pressure readings update continuously.
- Values respond to environmental changes.

## Results

The BME280 successfully provided environmental readings during testing and demonstration. Earlier development stages experienced issues due to incorrect sensor pin labeling, but replacement sensors and corrected wiring resolved the issue.

# Test 3 — USB Serial Communication Test

## Objective

Verify communication between the PCB and external computer software.

## Procedure

1. Connect the dedicated USB-C communication connector to the computer.
2. Verify the COM port appears on the computer.
3. Launch the Python application.
4. Open the serial connection.
5. Observe incoming environmental data.

## Expected Results

- Computer detects the device.
- Serial communication initializes successfully.
- Environmental data transfers continuously.
- No communication interruptions occur during operation.

## Results

USB serial communication successfully transferred environmental data from the PCB to the Python application during demonstration testing.

# Test 4 — Python Application Validation

## Objective

Verify that the Python application correctly processes and visualizes environmental data.

## Procedure

1. Launch the Python monitoring application.
2. Connect the serial port.

3. Observe incoming sensor readings.
4. Verify graph updates.
5. Verify prediction and weather classification logic.

## Expected Results

- Python application launches successfully.
- Environmental values display correctly.
- Graphs update continuously.
- Prediction logic processes incoming data.
- Weather classifications display correctly.

## Results

The Python application successfully received and displayed environmental readings during demonstration testing. The software was able to graph readings, estimate short-term trends, and classify weather conditions.

# Test 5 — ntfy Notification Validation

## Objective

Verify that environmental notifications can be sent to a phone using ntfy.

## Procedure

1. Run the Python application.
2. Trigger notification logic.
3. Observe notification behavior.
4. Verify phone receives ntfy message.

## Expected Results

- ntfy messages send successfully.
- Notifications appear on the phone.
- Notification cooldown logic prevents excessive alerts.

## Results

The ntfy notification system successfully demonstrated phone alert capability during testing.

# Test 6 — PCB Validation & Design Verification

## Objective

Verify that the PCB design is manufacturable and electrically valid.

## Procedure

1. Run ERC verification in KiCad.
2. Run DRC verification in KiCad.
3. Review routing and spacing.
4. Verify footprints and component placement.
5. Generate fabrication files.

## Expected Results

- ERC completes successfully.
- DRC completes successfully.
- PCB routing satisfies design rules.
- Gerber and drill files generate correctly.

## Results

The PCB design was successfully prepared for manufacturing. Gerber files, drill files, BOM documentation, and PCB ordering instructions were generated and organized for fabrication.

# Major Issues Encountered During Testing

## BME280 Sensor Damage

Some BME280 modules were damaged during early testing because the pins were incorrectly labeled or misidentified.

### Resolution

- Replacement sensors were obtained.
- Wiring was corrected.
- Sensor operation was revalidated.

## Missing Support Components

Early PCB review identified missing decoupling and support components.

### Resolution

- Additional capacitors were added.
- Support circuitry was updated.
- PCB design was reviewed again.

## PCB Routing Constraints

Routing congestion occurred during PCB layout development.

### Resolution

- Routing strategy was revised.
- 4-layer PCB concepts were explored.
- Via assignment and inner-layer routing techniques were tested.

# Overall Testing Conclusion

Testing successfully demonstrated:

- Environmental sensing functionality
- USB serial communication
- Python-based monitoring and graphing

- ntfy notification capability
- PCB manufacturability
- Embedded system integration

The project evolved significantly throughout testing and development. Early proof-of-concept work using a Raspberry Pi and DHT22 sensor eventually transitioned into a more realistic custom PCB-based embedded system using the ATmega328P-A and BME280.

The final system demonstrated successful environmental monitoring, software integration, manufacturing preparation, and practical embedded system development workflows.

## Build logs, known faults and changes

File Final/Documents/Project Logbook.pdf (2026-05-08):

# Project Logbook

## Phase 1 — Project Ideation & Planning (Late January – Early February)

- Project initiated in late January 2026
- Initial goal was to create a manufacturable embedded environmental monitoring system capable of measuring temperature, humidity, and atmospheric pressure
- Early concepts explored both Raspberry Pi and standalone embedded approaches before committing to a custom PCB architecture
- Selected the BME280 as the primary environmental sensor due to its ability to measure temperature, humidity, and atmospheric pressure in a single package
- Established GitHub repository for version control and organization
- Created the initial project definition document outlining objectives and proposed functionality

## Phase 2 — Proof of Concept & Sensor Validation (February – Early March)

- Used a Raspberry Pi temporarily as a proof-of-concept platform to validate environmental sensing and data collection
- Initial BME280 units were damaged during testing due to incorrect pin labeling and wiring confusion
- Multiple communication and wiring configurations were tested while troubleshooting sensor reliability
- DHT22 was temporarily used to validate the sensing workflow while replacement BME280 units were obtained
- Basic GUI and sensor visualization concepts were tested during this stage
- Proof-of-concept testing confirmed the feasibility of the environmental monitoring system before transitioning to standalone PCB development

## Phase 3 — Transition to Custom PCB Architecture (March 5th)

- During design review it became clear that a Raspberry Pi and touchscreen-based system would not reflect a realistic manufacturable embedded product
- Team agreed that a standalone embedded PCB design would better align with course goals and real engineering practices
- Decision made to redesign the system around the ATmega328P-A microcontroller

- Replaced the touchscreen GUI concept with USB serial communication and future phone notification capability
- Replacement BME280 sensor was correctly wired and validated, officially replacing the DHT22 proof-of-concept setup
- Project scope shifted toward a manufacturable PCB-focused embedded system

## Phase 4 — Schematic Design & Embedded Hardware Development (March – April)

- Schematic designed in KiCad using the ATmega328P-A as the primary processing unit
- Integrated the BME280 environmental sensor for temperature, humidity, and atmospheric pressure monitoring
- Used the available KiCad BME280 footprint and configured the sensor for I2C communication
- External crystal oscillator and 22pF load capacitors added to improve MCU timing stability
- Selected passive component values directly from component datasheets
- Added decoupling capacitors to reduce electrical noise
- Added ISP programming header for direct firmware flashing
- Added test points for probing, debugging, and future expansion
- Added status LED with current-limiting resistor for visual debugging

## Phase 5 — PCB Layout & Design Review (April 1st)

- Initial PCB layout completed and reviewed collaboratively
- Design review identified missing decoupling and bulk capacitors which were later added
- Routing constraints on a standard 2-layer PCB created congestion and limited trace flexibility
- Experimented with converting the design to a 4-layer stackup to learn inner-layer routing and via assignment techniques
- Learned how to assign vias to specific layers and route signals across internal copper layers
- ERC and DRC checks were performed and violations were resolved
- Generated 3D board renders to validate physical layout and component placement

## Phase 6 — Manufacturing Preparation (Late April – Early May)

- Generated Gerber fabrication files for all PCB layers
- Exported drill files for PCB manufacturing
- Compiled BOM containing component values, quantities, and part numbers
- Prepared PCB ordering instructions for fabrication services such as JLCPCB and PCBWay

- Organized repository structure with fabrication outputs, documentation, and software resources
- Verified the project was manufacturing-ready and capable of future assembly

## Phase 7 — Final System Integration & Presentation Preparation (May 7th)

- Updated the design to use two dedicated USB-C connectors — one for board power and one for communication with external software
- Began transitioning away from older screw terminal-only power concepts toward a cleaner and more modern interface design
- USB serial communication workflow finalized between the ATmega328P-A and external computer application
- Python-based data visualization and future weather trend prediction concepts integrated into the final presentation workflow
- Discussed future implementation ideas involving ntfy notifications, wireless monitoring, and predictive weather analysis
- Final presentation prepared demonstrating the complete engineering workflow from concept to manufacturable PCB
- Project finalized and submitted on May 7th, 2026

## Lessons Learned

- Hardware reliability must always be verified before full system integration
- Incorrect sensor pin labeling can quickly damage components and delay development
- Early proof-of-concept platforms are useful for validating ideas before committing to final hardware architecture
- Design reviews are extremely valuable and can identify missing hardware before manufacturing
- Proper decoupling and power stability are critical in embedded system design
- Learning 4-layer PCB routing significantly improved understanding of professional PCB workflows
- Real engineering development is highly iterative and improves through debugging, redesign, and refinement
- This project provided practical experience with schematic capture, PCB routing, manufacturing preparation, debugging, and embedded system integration

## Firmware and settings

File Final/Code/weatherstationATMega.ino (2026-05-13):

/*
  ECET 230 Personalized Weather Station
  ATmega328P-A / Arduino Uno style firmware

  What this does:
  - Reads BME280 temperature, humidity, and pressure over I2C
  - Sends data to the computer over Serial in CSV format:
      tempC,humidity,pressurehPa
  - This matches the Python GUI format:
      parts[0] = temperature in Celsius
      parts[1] = humidity in %RH
      parts[2] = pressure in hPa

  Wiring for ATmega328P-A / Arduino Uno:
  - BME280 VIN/VCC -> 3.3V
  - BME280 GND     -> GND
  - BME280 SDA     -> A4 / PC4 / SDA
  - BME280 SCL     -> A5 / PC5 / SCL
  - BME280 SDO     -> GND for address 0x76, or 3.3V for address 0x77

  Required Arduino libraries:
  - Adafruit BME280 Library
  - Adafruit Unified Sensor
*/

#include <Wire.h>
#include <Adafruit_Sensor.h>
#include <Adafruit_BME280.h>

#define SERIAL_BAUD 9600
#define READ_DELAY_MS 1000

// Try 0x76 first because SDO is usually connected to GND.
#define BME_ADDRESS_1 0x76
#define BME_ADDRESS_2 0x77

Adafruit_BME280 bme;
bool bmeFound = false;

void setup() {
  Serial.begin(SERIAL_BAUD);
  delay(1000);

  Wire.begin();

  if (bme.begin(BME_ADDRESS_1)) {
    bmeFound = true;
  } else if (bme.begin(BME_ADDRESS_2)) {
    bmeFound = true;
  } else {
    bmeFound = false;
  }

  if (!bmeFound) {
    Serial.println("BME280_ERROR");
  }
}

void loop() {
  if (!bmeFound) {
    Serial.println("BME280_ERROR");
    delay(2000);
    return;
  }

  float tempC = bme.readTemperature();       // Celsius
  float humidity = bme.readHumidity();       // %RH
  float pressureHpa = bme.readPressure() / 100.0F;  // Pa to hPa

  // Protect against bad readings.
  if (isnan(tempC) || isnan(humidity) || isnan(pressureHpa)) {
    Serial.println("READ_ERROR");
    delay(READ_DELAY_MS);
    return;
  }

  // Send clean CSV for the Python GUI.
  Serial.print(tempC, 2);
  Serial.print(",");
  Serial.print(humidity, 2);
  Serial.print(",");
  Serial.println(pressureHpa, 2);

  delay(READ_DELAY_MS);
}

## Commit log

2026-05-08 Create gerber
2026-05-13 Create Drill Files
2026-05-13 Create 3D View and Schematic.md
2026-05-13 Update 3D View and Schematic.md
